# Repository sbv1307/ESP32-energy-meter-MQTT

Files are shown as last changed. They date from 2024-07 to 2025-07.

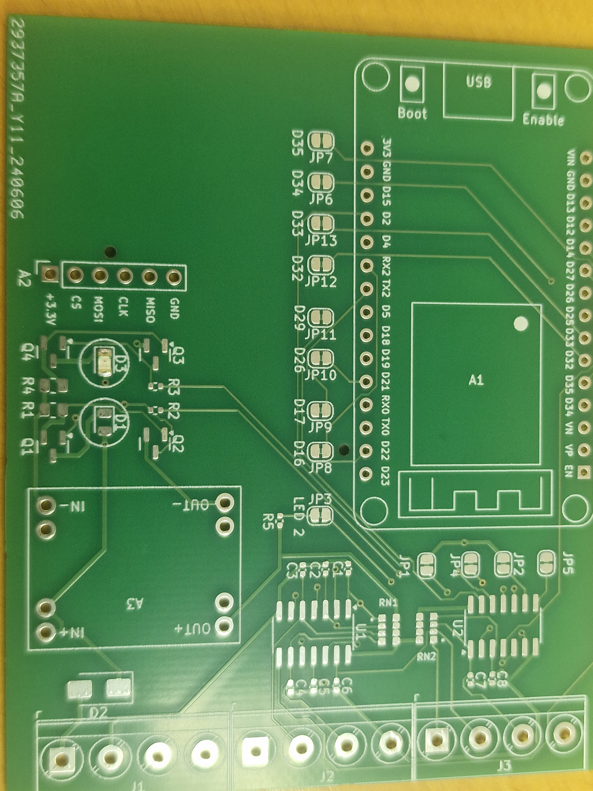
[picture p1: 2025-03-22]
Hardware/20240625_135143.jpg

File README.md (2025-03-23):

#  ESP32 energy meter MQTT interface

This is an Esp32 MQTT interface for up till eight energy meters, which has a pulse output like
Carlo Gavazzi Type EM23 DIN and EM111.

The interface will publish data to Home Assistant (HA) and Google sheets.

The interface will publish kWh (Totals), subtotals and a calculated power consumption to a 
MQTT broker for each energy meter.
The MQTT topic and payload will be compliant with the Home Assistant (HA) integration
MQTT sensor and number integration's.

The interface will publish kWh (Totals) and subtotals to Google Sheets at the time defined by SCHEDULE_HOUR and SCHEDULE_MINUTE in the privateConfig.h file.

Subtotals is a periodic count, resat every time kWh (Totals) and subtotals are published to Google Sheets or **true** is published to the topic:
````bash
energy/monitor_ESP32_48E72997D320/subtotal_reset
````
at the MQTT broker connected.

Upon reset of subtotals, the interface will publish kWh and subtotals to Google sheets through
a HTTPS GET request, using Google sheet’s doGet() function.

The Google sheet’s doGet() will add the values passed to the specific sheet.

Totals (kWh) can be preset through the MQTT interface following the JSON Document format.
Publishing Payload:
````bash
 {
   "Total" : pulse-counts
 }
````

to topic: 
````bash
energy/monitor_ESP32_48E72997D320/<Energy meter number***>/threshold
````

Then latest status message (e.g. the return message from the call to Google sheets) can be collectged
by subscribing to topic:
````bash
energy/monitor_ESP32_48E72997D320/status
````

To get information about the current running version, subscribe to topic:
````bash
energy/monitor_ESP32_48E72997D320/sketch_version
````

The Esp32 MQTT interface can be restarted (rebooed) by publishing **true** to the topic:

````bash
energy/monitor_ESP32_48E72997D320/restart
````

** **pulse-counts** in the number of pulses counted by the energy meter. It is calculated by the kWh,
shown on the energy meter multiplied be the number of pulses per kWh for the energy meter. 
 Pulses per kWh can be found in the documentation for the energy meter.

*** **Energy meter number** is a number 0..7 for the channel, on which the energy meter is connected.
The relation between energy meter and channel number is defined in the privateConfig.h file.

### SD Card failure.

In case the SD card fails to record energy meter counts, the message "SD-Error" will be added to the entries in Google sheet. A more detailed message will be published to:
````bash
energy/monitor_ESP32_48E72997D320/sketch_version
````

## Calculating Consumption
Consumption is calculated on every pulse registrated. 

The time between pulses (pulse-time) is calculated as current time minus the timestamp logged, at last occourence of a pulse. Present time is logged as timestamp for the calculating the next pulse-time.

In order to handle the situation, where consumption is reduced or even stopped, then pulse-time is continuously checked.

If the timesstamp logged plus two times the pulse-time is greater than the current time it indicate that consumption has dropped, and a new fictional Consumption is calculated. It will be presented as minus value to indicate, that it is fictional.

## Compiler options
Insæt følgende i **platform.ini**

````bash
; Larger buffer is needed for HomeAssistant discovery messages, which are quite large
build_flags = -D MQTT_MAX_PACKET_SIZE=1024
``````
## Project depended libraries.
##### Installed by: PlatformIO -> PIO Home -> Open -> Libraries -> Registry "Search Libraries"
**ArduinoJson** by Benoit Blanchon  - Version 7.0.1<br>
**PubSubClient** 0                  - Version 2.8

### Local kicad-library
The Local kicad-library located at [github](https://github.com/sbv1307/kicad-library) is required for the hardware. See the README.md for more information.

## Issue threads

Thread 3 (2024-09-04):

Stop running when SC card fails

sbv1307, 2024-09-04:
SW is designed to stop monitoring and enter an error indicating loop, flashing the LED to tell where in the sketch the failure were seen.
The reason for stop monitoring was, that meter totals could no longer be trusted if a power failure occurred.

Maybe a design change is required, where the SD failure is added as a messages to the sheet, The daily consumption will still be valid.

sbv1307, 2025-02-10:
Implemented in version 4.2.0

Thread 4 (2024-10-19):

Stopped updating Google Sheets after power outage,

sbv1307, 2024-10-19:
updating Home Assistant works. Subtotals is not reset - indicating that the update google sheets fails because of an issue with getMillisToNextTimeCheck() function.
getMillisToNextTimeCheck() can return -1 if it fails to getLocalTime, but this return value is never tested!

sbv1307, 2024-10-26:
millis() overrun will cause publsh to GS to stop. Implementing esp_timer_get_time() to return a timestamp in secunds til solve the overrun issue.
Changed the other usage of millis() as timestamps or changed to code to handle millis() overrun.

Closed 2024-10-26.

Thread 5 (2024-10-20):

PowerUp message only added once

sbv1307, 2024-10-20:
Then "Power Up" message added to Google Sheets (GS) are only added once, but it's not tested if this message actually cam through.
Then updateGoogleSheets() never tests the result from the call.
Power outage seems to cause a reboot, but GS is never updated.

Consider checking the response from google sheet ( httpCode = http.GET() ) before setting gsheetUpdated = true

sbv1307, 2024-10-26:
Fixed in version 4.1.0
Response for http.begin(urlFinal.c_str()) cal to GS is collected by httpCode = http.GET() but never tested for success.
 Test response for "200": httpCode = http.GET() = 200

Closed 2024-10-26.

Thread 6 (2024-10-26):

Temporary FIX to prevent more than one IQR to be registeret

sbv1307, 2024-10-26:
After adding HEX Schmitt triggers ti the IRQ pins, the Temporary FIX to prevent more than one IQR to be registeret in case more are fired, might not be needed anymore and will reduce IRO process time.

sbv1307, 2024-10-26:
Fixed in version 4.1.0:
Temporary fix in function 'void IRAM_ATTR store_IRQ_PIN(u_int8_t BIT_Reference)' removed after HEX Schmidt triggers are implemented in the hardware

sbv1307, 2024-10-26:
Fixed in version 4.1.0:
Temporary fix in function 'void IRAM_ATTR store_IRQ_PIN(u_int8_t BIT_Reference)' removed after HEX Schmidt triggers are implemented in the hardware

Closed 2024-10-26.

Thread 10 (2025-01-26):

LED_BUILTIN on when external LED is OFF

sbv1307, 2025-01-26:
Built in led turns on, when LED pin is HIGH.
External LED turns on when LED pin is LOW.

Solution: Modify hardware by adding one of the not used HAS Schmitriggers to the LED pin, and change firmware two places in the setup().

sbv1307, 2025-07-06:
HW modified: HES Schmittrigger added to IO2 / PIN 19 and Firmware modified so external LED now followes internal LED

Closed 2025-07-06.

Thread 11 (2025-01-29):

Slow SD actions cause issues

sbv1307, 2025-01-29:
If SD operations gets too slow, in can  cause issues, like:
- When power on during one or more energy meters provide pulses, then process to counting pulses never ends and Esp32 MQTT interface will never connect to WiFi.

Insert a limit for how long SD operations may take, before it is defined as an SD error, and SD operations not uwed.

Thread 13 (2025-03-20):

Power outage cause <Google sheet update to fail

sbv1307, 2025-03-20:
After af Power outage (every component (routers, switches, bridges, hubs ...) not running on UPS restarts) the  Esp32 MQTT interface failed to update Google sheets afterwards.
PS:  Esp32 MQTT interface runs on UPS, which might cause an issue, when then network connection is lost.

sbv1307, 2025-03-20:
Status message published to topic: energy/monitor_ESP32_48E72997D320/status is set as RETAINED, but seems lost at poweroutage.

sbv1307, 2025-03-22:
Issue: In case WiFI connect succeed, but the call to getLocalTime() fails - Then problem is NOT handled in the "Connect to WiFi if not connected" part of the main loop.
Further then function "unsigned long getsecondsToNextTimeCheck();" cannot return "-1", as it's an unsigned long... It will probably return a number, where the most significant bit is set to '1' ==>
/* >>>>>>>>>>>>>>>>>>>>>>>>>>> time check to scheculed Google update <<<<<<<<<<<<<<<<<<< */
  if (sec() > timeLastCheckedAt + secondsToNextTimeCheck)
Will no be true for avery long period of time ==> Update of Gogle sheets will not dhappen.

sbv1307, 2025-03-22:
Subscription to topic: energy/monitor_ESP32_48E72997D320/restart added. When true is published, ESP.restart() is called, which restarts the ESP module.
getsecondsToNextTimeCheck() now returns 60 (equal to one minute) in case of failure to call the timeserver getLocalTime().

Closed 2025-03-22.

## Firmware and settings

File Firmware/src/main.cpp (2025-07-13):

#include <Arduino.h>
#include <ArduinoJson.h>
#include <WiFi.h>
#include <HTTPClient.h>
#include <ESPmDNS.h>
#include <WiFiUdp.h>
#include <ArduinoOTA.h>
#include <PubSubClient.h>
#include <privateConfig.h>
#include "SD.h"
#include "SPI.h"
#include "time.h"

#define SKETCH_VERSION "Esp32 MQTT interface for Carlo Gavazzi energy meter - V4.4.1"

/*
 * This is an Esp32 MQTT interface for up till eight Carlo Gavazzi energy meters type
 * EM23 DIN and Type EM111.
 * 
 * The interface will publish data to Home Assistant (HA) and Google sheets (GS).
 *
 * The interface will publish kWh (Totals), subtotals and a calculated power consumption to a 
 * MQTT broker for each energy meter.
 * The MQTT topic and payload will be compliant with the (HA) integration
 * MQTT sensor and number integration's.
 * 
 * Subtotals is a periodic count, resat every time ‘true’ is published to the topic: 
 * ‘energy/monitor_ESP32_48E72997D320/subtotal_reset’ at the MQTT broker connected.
 * or
 * once every day, as specified in the privateConfig.h file.for when Google sheets are to be updated
 * 
 * Upon reset of subtotals, the interface will publish kWh and subtotals to GS through
 * a HTTPS GET request, using Google sheet’s doGet() function.
 *
 * The Google sheet’s doGet() will add the values passed to the specific sheet.
 *
 * Totals (kWh) can be preset through the MQTT interface following the JSON Document format.
 * Publishing Payload:
 *  {
 *    "Total" : pulse-counts**
 *  }
 * to topic: energy/monitor_ESP32_48E72997D320/<Energy meter number***>/threshold
 * 
 * Latest status can be seen by publis to topic:
 * energy/monitor_ESP32_48E72997D320/status
 * LED indications:
 * 
 * 
 * )** pulse-counts in the number of pulses counted by the energy meter. It is calculated by the kWh,
 * shown on the energy meter multiplied be the number of pulses per kWh for the energy meter. 
 *  Pulses per kWh can be found in the documentation for the energy meter.
 * )*** ‘Energy meter number’ is a number 0..7 for the channel, on which the energy meter is connected.
 * The relation between energy meter and channel number is defined in the privateConfig.h file. 
 */ 

/* Version history:
 *  1.0.0   Initial production version.
 *  2.0.0   Using MQTT broker as a storage for configuration data and energy meter counts, read/write from/to SD memory card has been implemnted.
 *          Struct data_t re-defined and split up to config_t, meta_t and data_t for optimal file read / write funktionality.
 *          Publishing totals, Subtotals and pulscorrections to MQTT has been replaced be write to SD Memory card.
 *  2.0.1   MQTT Reconnect bugfix
 *  2.0.2   serial removed as it is not needed.
 *  3.0.0   Publish data to GS based on epoch time and time collected from a time server
 *  3.0.1   BUGFIX: Interrupt ISR were attached to a non configured pin, which could cause an un-handled IRQ, which then cause infinite loop.
 *  3.1.0   Adding DEBUG compilor switch to investigate SD issue.
 *          -  Code re-arranged to comply with VS Code standard.
 *          -  Need to re-think the Idea for not using directories. The SD library uses short 8.3 names for files. This might be an issue.
 *             Data file sets now placed in directories.
 *          -  Startup delay for 10 sec. introduced, before accessinmg the SD Card. This is to prevent SD Card issues while connecting the device to power.
 *             While onnecting the device to power will in moast cases cause multible power failures (dis-connections), before the power is stable.
 *          -  Test time stamp for IRQ. If Last IRQ is less 500 millis, IRQ is ignored. 
 *  4.0.0   Firmware modified to match hardware. 
 *          -  Pull up is no longer required, as the new hardware inclcudes hex schmidt-triggers.
 *          -  IRQ's are now tgriggered my a raising pulse.
 *          -  Status LED is lit when GPIO pin is LOW
 * 4.1.0    BUGFIX:
 *          - Issue: Stopped updating Google Sheets after power outage. 
 *            Sketch runs, Values published to MQTT, Sketch handles MQTT requests. Updating GS does not happen!
 *            - Investigate millis() overrun.
 *              millis() overrun will cause publsh to GS to stop. Implementing esp_timer_get_time() to return a timestamp in secunds til solve the overrun issue.
 *              Changed the other usage of millis() as timestamps or changed to code to handle millis() overrun.
 *          - Issue: PowerUp message only added once
 *            Changed logic to keep adding PowerUp message until successful call Google Sheets and adding WiFiReconnect message un WiFi reconnect.
 *          - Response for http.begin(urlFinal.c_str()) cal to GS is collected by httpCode = http.GET() but never tested for success.
 *            Test response for "200": httpCode = http.GET() = 200
 *          - Issue: Temporary FIX to prevent more than one IQR to be registeret.
 *            Temporary fix in function 'void IRAM_ATTR store_IRQ_PIN(u_int8_t BIT_Reference)' removed after HEX Schmidt triggers are implemented in the hardware
 * 4.1.1    BUGFIX:
 *         - Issue: Not all Home Assistant (HA) configurations are published. #8
 *         - Issue: "Forbrug" is published as 0 (zero) #9
 * 4.2.0    Enhancements:
 *        - Issue: Stop running when SC card fails #3
 * 4.3.0    Bugfix:
 *       - Issue: Power outage cause <Google sheet update to fail #13
 * 4.4.0   Enhancements:
 *       - Issue: LED_BOILTIN on when external LED is OFF #10
 * 4.4.1   enhancements:
 *       - Issue: Walues not published before activity after restart. #14
 *          
 * Boot analysis:
 * Esp32 MQTT interface for Carlo Gavazzi energy meter - V2.0.0
 * Time to set pinmode and led: 0
 * Time to initialise globals and arm ISR: 2
 * Time to initialise SD: 345 /  10
 * Time to read configuration 7
 * Time to initialise test structure version  0
 * Time to read datafiles 1611
 * Time to write new configuration file: 327 / 31
 * Time to write new data: 4162
 * ### Failed connection to WiFi ########
 *    Time to connect to WiFi: 155
 *    Time to wait for failed connection to WiFi: 2501
 *    Time to connect to WiFi: 31
 *    Time to wait for failed connection to WiFi: 1
 *    Time to connect to WiFi: 18
 *    Time to wait for failed connection to WiFi: 0
 * ###  Sucessfull connection to WiFi, Failed connect to MQTT  ###
 *    Time to connect to WiFi: 155
 *    Time to wait for successfull connection to WiFi: 2001
 * Time to start OTA: 18
 * Time to failed connect to MQTT: 3006
 * Time to failed connect to MQTT: 3006
 * 
 * Suggestions to tune the boot process: 
 * - Look into the use of SdFat library and the use of fixed CS instead of SD library, this might speed up the SD Card operations.
 *   Might be an issue if a new config file is required (Changes done to the configuraion will require a scan throuh all existing files)
 * - Give the process time to handle incomming IRQ's between WiFi connect and MQTT connect. (DONE ny ignoring connet attempts if IRQ's available)
 * 
 *  Future versions:
 *  
 * 
 *  - Ideas: as writes to SD for each Energy meter count will be intensive, implement a method to write thise data to diffenret locations.  
 *           Considder to implement rename of data file instead of creating new datafiles and keeping track of old to avoid re-use of SD memory location.
 *           If NTP Server will give date and time, datafiles can be renamed to date and time and the sam data file names can be used. 
 *  - Finetune MQTT_MAX_PACKET_SIZE in platformio.ini. Definition: MQTT_MAX_PACKET_SIZE < MQTT_MAX_HEADER_SIZE + 2 + strlen(topic) + payload length
 *    where MQTT_MAX_HEADER_SIZE is defined as 5.
 *  - Reduce boot time to reduce loss of Energy meter pulses. Might require use of SdFat library  instead of SD library.
 *  - Imlement ESP.restart() if required. Consider to implement EEPROM.write() https://randomnerdtutorials.com/esp32-flash-memory/
 *    during call to ESP.resart(). Writes for every update will kill flash memory. 
 *  - Configurable parameters - Configuration thrount MQTT:
 *    - Google Sheet ID
 */

/*
 * ######################################################################################################################################
 * ######################################################################################################################################
 *                       V  A  R  I  A  B  L  E      D  E  F  I  N  A  I  T  O  N  S
 * ######################################################################################################################################
 * ######################################################################################################################################
 */


#define CONFIGURATON_VERSION 5
/* WiFi and MQTT connect attempt issues. 
 * IRQ's will be registrated, but the counters for will not be updated during the calls to WiFi and MQTT connect. If more than one pulse
 * from then same meter arrives, it will be lost if these calls takes up too much time. Setting a long connect postpone will reduce the loss
 * of pulses
*/
#define WIFI_CONNECT_POSTPONE 30        // Number of seconds between WiFi connect attempts, when WiFi.begin fails to connect.
#define MQTT_CONNECT_POSTPONE 30        // Number of seconds between MQTT connect dattempts, when MQTT connect fails to connect.
#define BLIP 100                        // Time in milliseconds the LED will blink
#define MIN_CONSUMPTION 25              // Define the minimum powerconsumption published before publishing 0
                                        // See '>>>    Pulse time check  <<<' in the last part of the loop() for further details.
#define RETAINED true                   // Used in MQTT puplications. Can be changed during development and bugfixing.
#define UNRETAINED false
#define MAX_NO_OF_CHANNELS 8
#define MAX_NUMBER_OF_WRITES 65500      // Number of writes made to data file / SD Card, before new set of datafiles will be used (MAX 2^16)

/* Configurable MQTT difinitions
 * These definitions can be changed to suitable nanes.
 * Chagens might effect other inntegrations and configurations in HA!
 */

const String  MQTT_CLIENT = "Carlo-Gavazzi-Energy-Meters_";       // mqtt client_id prefix. Will be suffixed with Esp32 mac to make it unique

const String  MQTT_PREFIX                   = "energy/";              // include tailing '/' in prefix!
const String  MQTT_DEVICE_NAME              = "monitor_ESP32_";       // only alfanumeric and no '/'
const String  MQTT_DISCOVERY_PREFIX         = "homeassistant/";       // include tailing '/' in discovery prefix!
const String  MQTT_PREFIX_DEVICE            = "meter_";
const String  MQTT_ONLINE                   = "/online"; 
const String  MQTT_SENSOR_ENERG_ENTITYNAME  = "Subtotal";  // name dislayed in HA device. No special chars, no spaces
const String  MQTT_SENSOR_POWER_ENTITYNAME  = "Forbrug";   // name dislayed in HA device. No special chars, no spaces
const String  MQTT_NUMBER_ENERG_ENTITYNAME  = "Total";     // name dislayed in HA device. No special chars, no spaces
const String  MQTT_PULSTIME_CORRECTION      = "pulscorr";
const String  MQTT_SKTECH_VERSION           = "/sketch_version";
const String  MQTT_SUFFIX_STATE             = "/state";
const String  MQTT_SUFFIX_CONSUMPTION       = "/watt_consumption";
// MQTT Subscription topics
const String  MQTT_SUFFIX_TOTAL_TRESHOLD    = "/threshold";
const String  MQTT_SUFFIX_SUBTOTAL_RESET    = "/subtotal_reset";
const String  MQTT_SUFFIX_CONFIG            = "/config";
const String  MQTT_SUFFIX_STATUS            = "status";
const String  MQTT_SUFFIX_ESP_RESTART       = "/restart";

/*  None configurable MQTT definitions
 *  These definitions are all defined in 'HomeAssistand -> MQTT' and cannot be changed.
*/
const String  MQTT_SENSOR_COMPONENT         = "sensor";
const String  MQTT_NUMBER_COMPONENT         = "number";
const String  MQTT_ENERGY_DEVICECLASS       = "energy";
const String  MQTT_POWER_DEVICECLASS        = "power";

/*
 * File configurations
 * There will be one configuration file and a data file for each energy meter connected (Number of energy meters is defined in privateConfig.h).
 * As writes to data files will occour on every pulse registered, writes to the SD Card will be intensive.
 * To prevent SD Card failures, a new set of datafiles will be created at every reboot or for every 65.500** pulses counted.
 * Each data file set will be created in a directory, which will have an ending number 0 - 2^16 (65536 the max for a uint16_t)
 * Data files will have an ending number 0 - (MAX_NO_OF_CHANNELS - 1).
 * 
 * ** 65.500 pulses will be equal tp 65,50kWh registered on a Carlo Gavazzi type EM111 energy meter.
 * 
 */
const String CONFIGURATION_FILENAME = "/config.cfg ";   // Filenames has to start with '/'
const String DATAFILESET_POSTFIX    = "/fs_v2-";           // Will bee the directory name
const String FILENAME_POSTFIX       = "/df-";           // Leading '/'. 
const String FILENAME_SUFFIX        = ".dat";           //

/*
 * Time server configuration
 */

const char* ntpServer = "pool.ntp.org";
const long  gmtOffset_sec = 3600;
const int   daylightOffset_sec = 3600;

String mqttDeviceNameWithMac;
String mqttClientWithMac;
String errorMessages[] = {
                          "0 SD Card not initialized", 			        // Error index 0
                          "1 open / Creating configuration file", 	// Error index 1
                          "2 writing configuration file", 	      	// Error index 2
                          "3 creating directory for data files",    // Error index 3
                          "4 open / creating data files", 	      	// Error index 4
                          "5 writing data files", 		            	// Error index 5
                          "6 Failed to update number of writes", 		// Error index 6
                          "7 SD operation too slow" 	              // Error index 7
                         };

int errorIndex = 0;
int previousErrorIndex = 0;

uint16_t blip = BLIP;
uint8_t GlobalIRQ_PIN_index = 0;
uint16_t numberOfWrites = 0;
uint8_t GoogleSheetMessageIndex = 1;  // Setting message in GS to PowerUp

// Define array of GPIO pin numbers used for IRQ.
const uint8_t channelPin[MAX_NO_OF_CHANNELS] = {private_Metr1_GPIO,private_Metr2_GPIO,private_Metr3_GPIO,private_Metr4_GPIO,
                                                private_Metr5_GPIO,private_Metr6_GPIO,private_Metr7_GPIO,private_Metr8_GPIO};  

bool configurationPublished[PRIVATE_NO_OF_CHANNELS];  // a flag for publishing the configuration to HA if required.
bool esp32Connected = false;                          // Is true, when connected to WiFi and MQTT Broker
bool LED_ToggledState = false; 
bool LED_Invertred = false;
bool SD_Failed = false;                               // Set to true if SD Card fails

WiFiClient wifiClient;
PubSubClient mqttClient(wifiClient);
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
void loop() {
  Serial.print("Time: ");
  myTime = sec();

  Serial.println(myTime); // prints time since program started
  delay(1000);          // wait a second so as not to send massive amounts of data
}
 *
 */
unsigned long sec()
{
  int64_t m = esp_timer_get_time();
  unsigned long s = m / 1000000;
  return s;
}

/*
 * ###################################################################################################
 *              P U B L I S H   M Q T T   E N E R G Y   C O N F I G U R A T I O N
 * ###################################################################################################
 * 
 * component can take the values: "sensor" or "number"
 * device_class can take the values "energy" or "power"
*/
/*  Eksempel på Topic og Payload for MQTT sensor integration, deviceClass = "energy":
 *  Where : Component = MQTT_SENSOR_COMPONENT and PIN_reference = 0
 *
 *  energyTopic: homeassistant/sensor/energy/meter_0/config
 *  energyMessage:
 *  {
 *    "name": "Subtotal",
 *    "state_topic": "homeassistant/energy/meter_0/state",
 *    "device_class": "energy",
 *    "unit_of_measurement": "kWh",
 *    "unique_id": "Subtotal_meter_0",
 *    "value_template": "{{ value_json.Subtotal}}",
 *    "device":{
 *      "identifiers":[
 *        "meter_0"
 *      ],
 *      "name": "Energi - Varmepumpe SMO 40 E1"
 *    }
 *  }
 */
/*  Eksempel på Topic og Payload for MQTT sensor integration, deviceClass = "power":
 *  Where : Component = MQTT_SENSOR_COMPONENT and PIN_reference = 0
 *
 *  energyTopic: homeassistant/sensor/energy/meter_0/config
 *  energyMessage:
 *  {
 *    "name": "Forbrug",
 *    "state_topic": "homeassistant/energy/meter_0/state",
 *    "device_class": "power",
 *    "unit_of_measurement": "W",
 *    "unique_id": "Forbrug_meter_0",
 *    "value_template": "{{ value_json.Forbrug}}",
 *    "device":{
 *      "identifiers":[
 *        "meter_0"
 *      ],
 *      "name": "Energi - Varmepumpe SMO 40 E1"
 *     }
 *  }
 */
/*  Eksempel på Topic og Payload for MQTT Numner integration, deviceClass = "energy":
 *  Where : Component = MQTT_NUMBER_COMPONENT and PIN_reference = 0
 *
 *  energyTopic: homeassistant/number/energy/meter_0/config
 *  energyMessage:
 *  {
 *    "command_topic" : "energy/monitor_ESP32_48E72997D320/threshold",
 *    "command_template" : {"Total": {{ value }} },
 *    "max" : "99999.99",
 *    "min" : "0.0",
 *    "name": "Total",
 *    "state_topic": "homeassistant/energy/meter_0/state",
 *    "device_class": "energy",
 *    "unit_of_measurement": "kWh",
 *    "unique_id": "Total_meter_0",
 *    "value_template": "{{ value_json.Total}}",
 *    "device":{
 *      "identifiers":[
 *        "meter_0"
 *      ],
 *      "name": "Energi - Varmepumpe SMO 40 E1"
 *    }
 *  }
 * 
 */
/*  Eksempel på Topic og Payload for opdatering af state (Værdier)
Topic_ homeassistant/energy/meter_0/state
Payload:
{
	"Subtotal" : "123",
  "Forbrug" : "456",
  "Total" : "789"
}
 */
void publishMqttEnergyConfigJson( String component, String entityName, String unitOfMesurement, String deviceClass, u_int8_t PIN_reference)
{
  uint8_t payload[1024];
  JsonDocument doc;
  String energyMeter = String( private_energyMeters[PIN_reference]);

  if ( component == MQTT_NUMBER_COMPONENT & deviceClass == MQTT_ENERGY_DEVICECLASS)
  {
    doc["command_topic"] = String(MQTT_PREFIX + mqttDeviceNameWithMac + "/" + PIN_reference + MQTT_SUFFIX_TOTAL_TRESHOLD);
    doc["command_template"] = String("{\"" + entityName + "\": {{ value }} }");
    doc["max"] = 99999.99;
    doc["min"] = 0.0;
    doc["step"] = 0.01;
  }
  doc["name"] = entityName;
  doc["state_topic"] = String(MQTT_DISCOVERY_PREFIX + MQTT_PREFIX + MQTT_PREFIX_DEVICE + PIN_reference + MQTT_SUFFIX_STATE);
  doc["availability_topic"] = String(MQTT_PREFIX + mqttDeviceNameWithMac + MQTT_ONLINE);
  doc["payload_available"] = "True";
  doc["payload_not_available"] = "False";
  doc["device_class"] = deviceClass;
  doc["unit_of_measurement"] = unitOfMesurement;
  doc["unique_id"] = String(entityName + "_" + MQTT_PREFIX_DEVICE + PIN_reference);
  doc["qos"] = 0;

  if ( component == MQTT_SENSOR_COMPONENT & deviceClass == MQTT_POWER_DEVICECLASS)
    doc["value_template"] = String("{{ value_json." + entityName + "}}");
  else 
    doc["value_template"] = String("{{ value_json." + entityName + " | round(2)}}");

  JsonObject device = doc["device"].to<JsonObject>();

  device["identifiers"][0] = String(MQTT_PREFIX_DEVICE + PIN_reference);
  device["name"] = String("Energi - " + energyMeter);

  size_t length = serializeJson(doc, payload);
  String energyTopic = String( MQTT_DISCOVERY_PREFIX + component + "/" + deviceClass + "/" + MQTT_PREFIX_DEVICE + PIN_reference + "/config");

  mqttClient.publish(energyTopic.c_str(), payload, length, UNRETAINED);
}
/*
 * ###################################################################################################
 *                       P U B L I S H   M Q T T   C O N F I G U R A T I O N S  
 * ###################################################################################################
*/
void publishMqttConfigurations( uint8_t device) {

  publishMqttEnergyConfigJson(MQTT_SENSOR_COMPONENT, MQTT_SENSOR_ENERG_ENTITYNAME, "kWh", MQTT_ENERGY_DEVICECLASS, device);
  publishMqttEnergyConfigJson(MQTT_SENSOR_COMPONENT, MQTT_SENSOR_POWER_ENTITYNAME, "W", MQTT_POWER_DEVICECLASS, device);
  publishMqttEnergyConfigJson(MQTT_NUMBER_COMPONENT, MQTT_NUMBER_ENERG_ENTITYNAME, "kWh", MQTT_ENERGY_DEVICECLASS, device);

  configurationPublished[device] = true;
}
/*
 * ###################################################################################################
 *                       P U B L I S H   S E N S O R   J S O N
 * ###################################################################################################
*/
/*  Eksempel på Topic og Payload for opdatering af state (Værdier)
Topic_ homeassistant/energy/meter_0/state
Payload:
{
	"Subtotal" : "123",
  "Forbrug" : "456",
  "Total" : "789"
} 
*/
void publishSensorJson( long powerConsumption, uint8_t IRQ_PIN_index)
{
  uint8_t payload[256];
  JsonDocument doc;

  doc[MQTT_SENSOR_ENERG_ENTITYNAME] = float(meterData[IRQ_PIN_index].pulseSubTotal) / float(interfaceConfig.pulse_per_kWh[IRQ_PIN_index]);
  doc[MQTT_SENSOR_POWER_ENTITYNAME] = powerConsumption;
  doc[MQTT_NUMBER_ENERG_ENTITYNAME] = float(meterData[IRQ_PIN_index].pulseTotal) / float(interfaceConfig.pulse_per_kWh[IRQ_PIN_index]);

  size_t length = serializeJson(doc, payload);
  String sensorTopic = String(MQTT_DISCOVERY_PREFIX + MQTT_PREFIX + MQTT_PREFIX_DEVICE + IRQ_PIN_index + MQTT_SUFFIX_STATE);

  mqttClient.publish(sensorTopic.c_str(), payload, length, UNRETAINED);
}
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

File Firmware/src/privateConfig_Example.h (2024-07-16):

/*
 * Private configuration file for projekt: "Esp32 MQTT interface for Carlo Gavazzi energy meter - V2.0.2"
 * ######################################################################################################################################
 * ######################################################################################################################################
 *                       C  O  N  F  I  G  U  T  A  B  L  E       D  E  F  I  N  I  T  I  O  N  S
 * ######################################################################################################################################
 * ######################################################################################################################################
*/

//How to show a list of Wi-Fi connections: netsh wlan show profiles

const String   PRIVATE_WIFI_SSID    = "ESSID Name";         // wifi ssid
const String   PRIVATE_WIFI_PASS    = "SSID Pasword";     // wifi password

const String   PRIVATE_MQTT_SERVER  = "nnn.nnn.nnn.nnn"; // mqtt server address 

const String   PRIVATE_MQTT_USER    = "";       // mqtt user. Use "" for no username
const String   PRIVATE_MQTT_PASS    = "";       // mqtt password. Use "" for no password
const uint16_t PRIVATE_MQTT_PORT    = 1883;     // mqtt port (default is 1883)

/*
 * Define which GPIO pin numbers are used for IRQ pin / Energy Meter.

 * These eight GPIO's can all be configured as INPUT_PULLUP, which mens that no external componenst are required
 * Do NOT remove any of the definations! If less than eight GPIO pin's are used, keep the defination for the unused
 * GPIO's as it is.
 */
#define private_Metr1_GPIO   4
#define private_Metr2_GPIO   12
#define private_Metr3_GPIO   13
#define private_Metr4_GPIO   14
#define private_Metr5_GPIO   15
#define private_Metr6_GPIO   25
#define private_Metr7_GPIO   26
#define private_Metr8_GPIO   27

/*
 *  Google sheets script id. 
 *  Find the schript ID from Google Apps Script -> Deploy -> Manage Deployments -> (Select Deployment) -> Copy ID part of Web Url.
 *  Example: https://script.google.com/macros/s/2AAU82PQwSI9opXFDJ1CNyhjA0fiJGPXuxYloCgRnfN242lnb2r6SgkkXSUDRdhWijJDq3GyWv/exec
 *  ID =                                        ^^^^^^^^^^^^^^^^^^^^^^^^^^^^^^^^^^^^^^^^^^^^^^^^^^^^^^^^^^^^^^^^^^^^^^^^^^
 *  The Google sheets script id entered here is an example!
*/
bool PRIVATE_UPDATE_GOOGLE_SHEET = true;   // Set the flag to true if data are to be added to Google sheets
const String PRIVATE_GOOGLE_SCRIPT_ID = "2AAU82PQwSI9opXFDJ1CNyhjA0fiJGPXuxYloCgRnfN242lnb2r6SgkkXSUDRdhWijJDq3GyWv";

/*
 * Define when Google sheets are to be updated
 */
#define SCHEDULE_MINUTE  0
#define SCHEDULE_HOUR  0

// Number of energy meters connected. 
// Be sure to modify the values for next variable (private_default_pulse_per_kWh).
#define PRIVATE_NO_OF_CHANNELS 8

// Define default number of pulses per kWh for each energy meter.

uint16_t private_default_pulse_per_kWh[PRIVATE_NO_OF_CHANNELS] = {1000,1000,1000,1000,1000,100,100,100};

char * private_energyMeters[] = {
           (char*) "Name precented in Home Assistant for energy meter connected to Metr1_GPIO",
           (char*) "Name precented in Home Assistant for energy meter connected to Metr2_GPIO",
           (char*) "Name precented in Home Assistant for energy meter connected to Metr3_GPIO",
           (char*) "Name precented in Home Assistant for energy meter connected to Metr4_GPIO",
           (char*) "Name precented in Home Assistant for energy meter connected to Metr5_GPIO",
           (char*) "Name precented in Home Assistant for energy meter connected to Metr6_GPIO",
           (char*) "Name precented in Home Assistant for energy meter connected to Metr7_GPIO",
           (char*) "Name precented in Home Assistant for energy meter connected to Metr8_GPIO",
};

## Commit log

2024-04-14 BUGFIX - MQTT reconnect issue fixed
    [main.cpp, privateConfig_Example.h]
2024-04-30 GFIX: Interrupt ISR were attached to a non configured pin, which could cause an un-handled IRQ, which then cause infinite loop.
2024-05-25 FIRM: Code re-arranged, Debug switch added and Datafiles split into directories
2024-07-16 FRM: DEBUG option added, code re-arranged, use of directories on SD implemented
    [BOM.csv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]
2024-07-16 remove Hardware/JLCPCB
    [BOM.csv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]
2024-07-16 remove Hardware/library
    [BOM.csv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]
2024-10-26 FRM: BUGFIX millis() overrun issue and Google Sheet update
    [main.cpp]
2025-01-19 FRM Bugfixes - millis overrun
    [main.cpp]
2025-01-28 FRM: ISSUE: Stop running when SC card fails #3 implemented
    [main.cpp]
2025-01-28 FRM: Stop running when SC card fails #3 impl.
    [main.cpp]
2025-01-29 FRM: Bugfixes from db4.2.0-SD_Fail implemented.
    [main.cpp]
2025-03-22 HW: PCB Picture added
2025-03-23 FRM: Power outage cause <Google sheet update to fail #13
    [main.cpp]
2025-07-05 FRM: External LED now follows internal LED #10
2025-07-06 HW HEX Schmittrigger entered
    [energiRegistrationForHA.kicad_sch]
